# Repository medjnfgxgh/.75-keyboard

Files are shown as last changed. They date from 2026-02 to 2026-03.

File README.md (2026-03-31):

# .75-keyboard
An 83 key mechanical keyboard with a rotary encoder for volume and brightness. This was designed to be similar to a 75% keyboard.

### Why?
I was complaining to my friend about how terrible the keyboards in the computer labs at school are, and he suggested I bring my own. One problem, I don't have a spare keyboard. "Just make one", he said, "How hard could it be?". This was very clearly a joke but it did give me an idea for my next project, why not make my very own mechanical keyboard. It would test my CAD and PCB design skills, as well as my soldering, 3d printing and programming knowledge. After a little bit of research, I landed on my design with 83 keys and a rotary encoder.

8fcc9e12-a2cc-4154-a71c-1df4aa7ac567

## The design


## Schematic


## PCB


## Case
14d5399e-915a-4103-ba52-5c0a4543586c

# BOM
| Name | QTY | Cost | Link |
|---|-----|---|---|
|Rasberry Pi Pico welded C |  1  |$2.63 |[buy](https://www.aliexpress.com/item/1005005617180169.html)|
|Cherry MX switches |  9  |$2.33 |[buy](https://www.aliexpress.com/item/1005004341695529.html)|
|Stabilisers |  1  |$6.82 |[buy](https://www.aliexpress.com/item/1005007041109896.html)|
|Key Caps |  1  |$21.62|[buy](https://www.aliexpress.com/item/1005007360831985.html)|
|diodes |  1  |$4.48 |[buy](https://www.aliexpress.com/item/1005008994213870.html)|
|EC11 |  1  |$2.27 |[buy](https://www.aliexpress.com/item/1005007644083514.html)|
|Brass inserts |  1  |$4.56 |[buy](https://www.aliexpress.com/item/1005006071488810.html)|
|Screws |  1  |$6.38 |[buy](https://www.aliexpress.com/item/1005006674812661.html)|
|Female Headers |  1  |$3.34 |[buy](https://www.aliexpress.com/item/4001198421663.html)|
|subtotal |  1  |$73.07|
|Discounts |  1  |$-11.5|
|shipping |  1  |$7.39
|--------------------------|-----|------|-----|
|AliExpress total |  1  |$68.96|
|PCB |  1  |$35.32|
|--------------------------|-----|------|-----|
|TOTAL |  1  |$104.28|

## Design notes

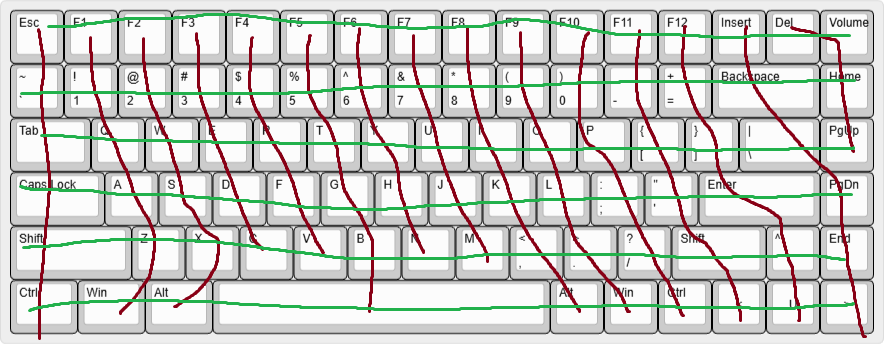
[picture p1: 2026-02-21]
Design/keyboard-layout-matrix.png

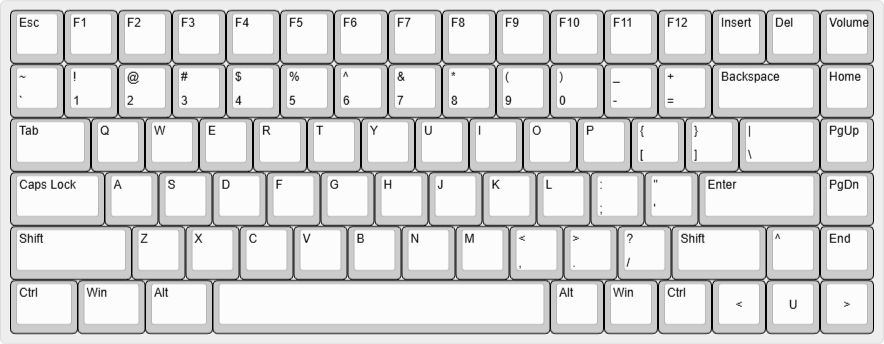
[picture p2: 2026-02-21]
Design/keyboard-layout.png

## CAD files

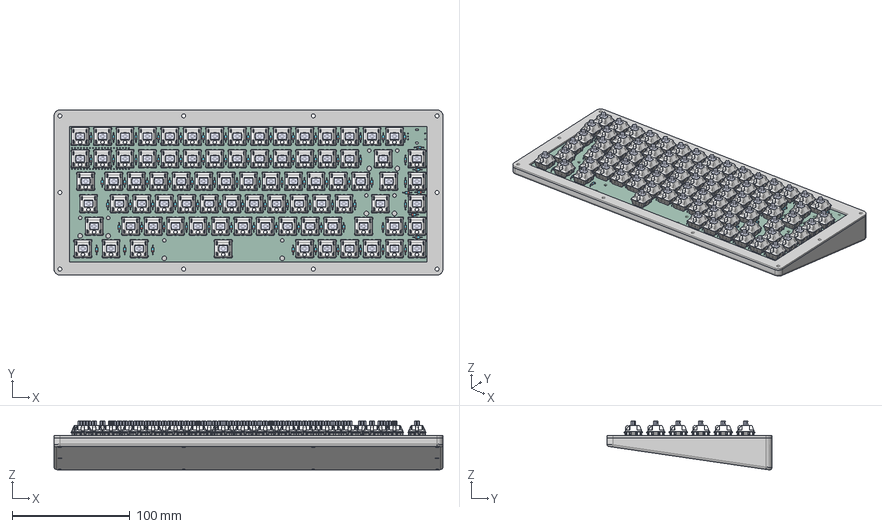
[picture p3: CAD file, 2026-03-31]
CAD/assembled.step
330.0 x 140.0 x 41.5 mm
D_DO-35_SOD27_P7.62mm_Horizontal x 84
Bottom x 83
Pulsador x 83
Top x 83
Pieza5^Cherry MX x 83
Pin1 x 83
Pin2 x 83
Led 3mm_trans x 83
PinSocket_1x20_P2.54mm_Vertical x 2
.75-keyboard-PCB_PCB

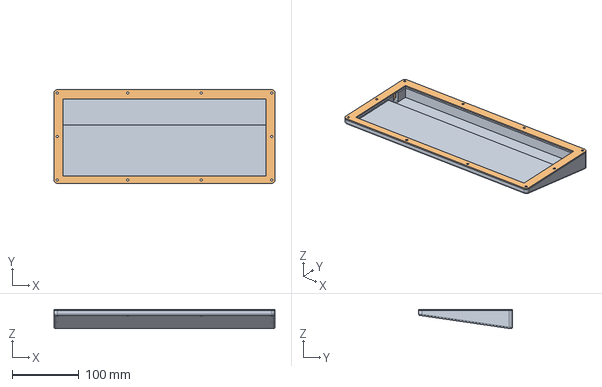
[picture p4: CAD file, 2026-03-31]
CAD/.75 keyboard cad.step
330.0 x 140.0 x 29.1 mm
base
Lid

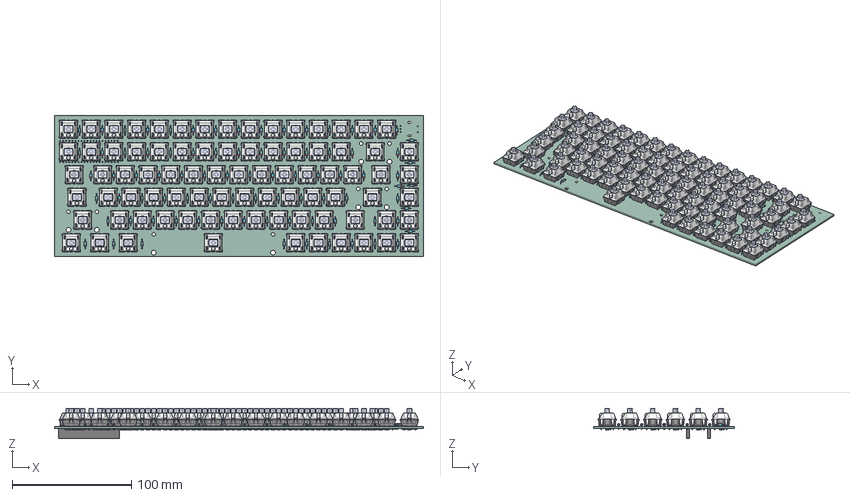
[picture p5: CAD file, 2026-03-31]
PCB/.75-keyboard-PCB.step
309.3 x 118.6 x 25.2 mm
D_DO-35_SOD27_P7.62mm_Horizontal x 84
Bottom x 82
Pulsador x 82
Top x 82
Pieza5^Cherry MX x 82
Pin1 x 82
Pin2 x 82
Led 3mm_trans x 82
PinSocket_1x20_P2.54mm_Vertical x 2
.75-keyboard-PCB_PCB

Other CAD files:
CAD/.75-keyboard-PCB.step

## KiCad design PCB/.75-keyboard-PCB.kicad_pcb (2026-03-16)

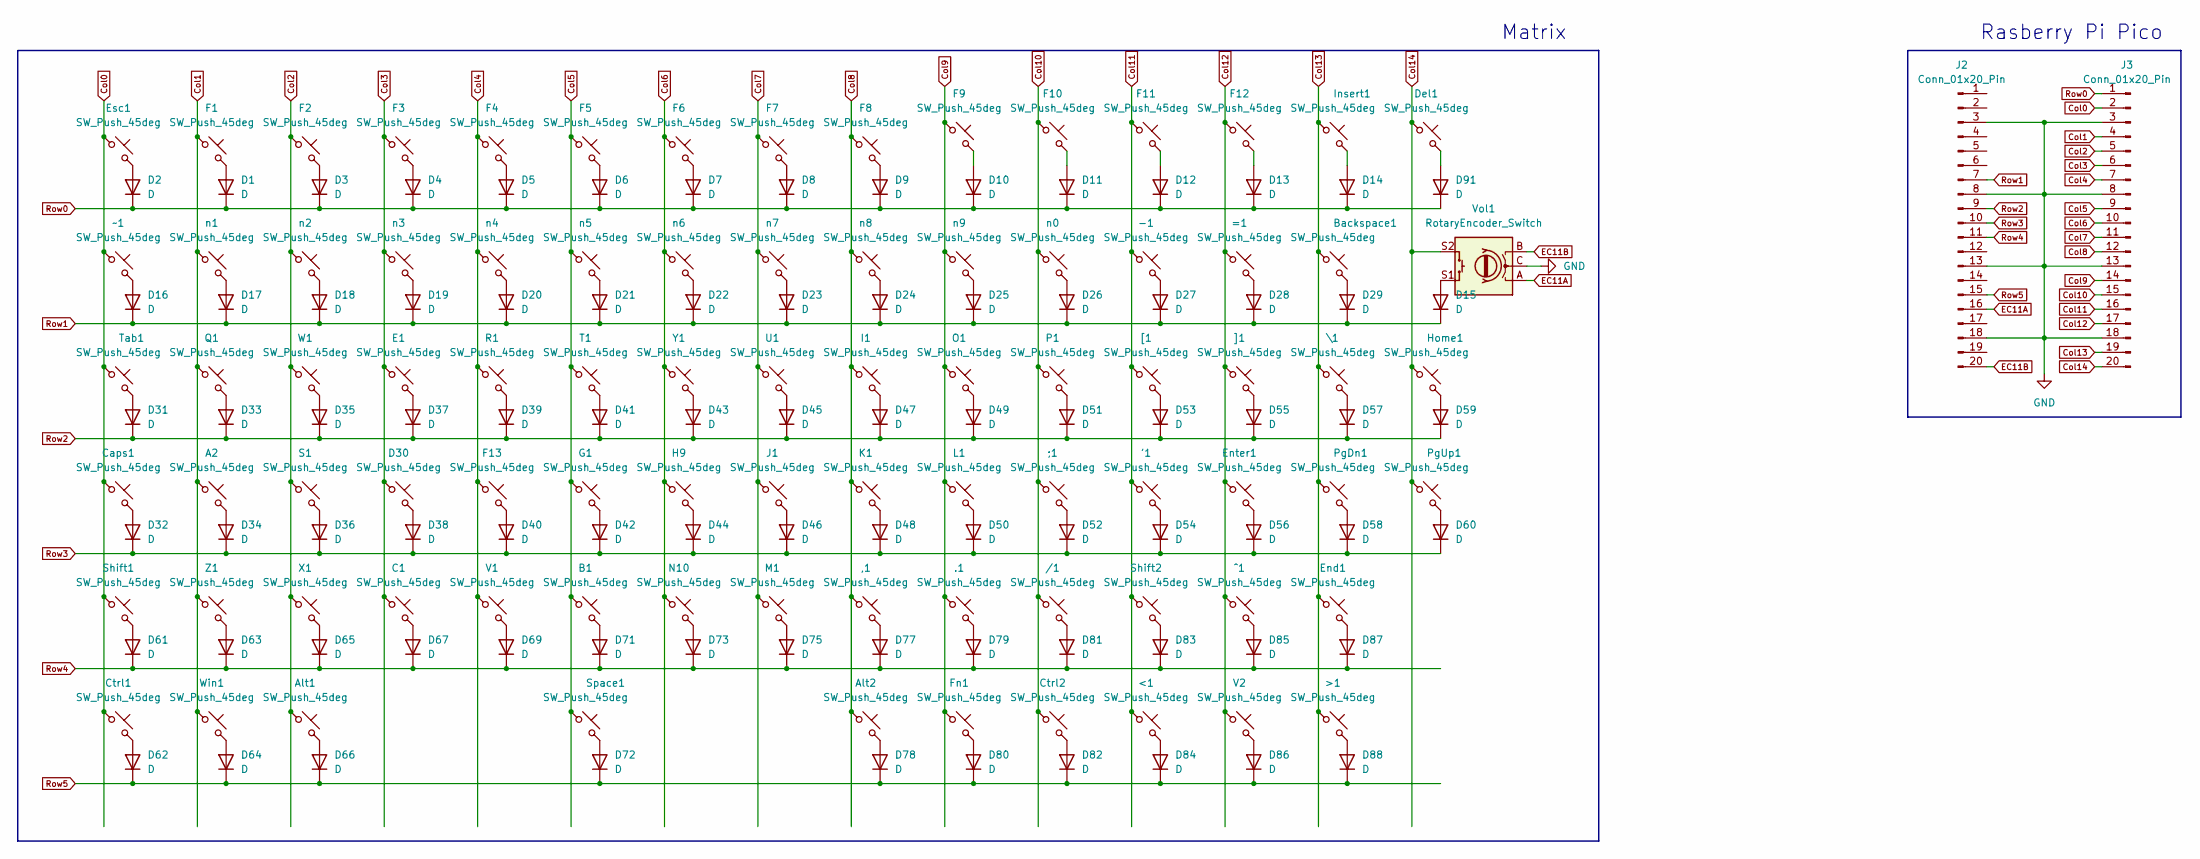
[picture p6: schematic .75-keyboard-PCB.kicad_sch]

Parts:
'1: SW_Push_45deg; 3DSW_Cherry_MX_1.00u_PCB
,1: SW_Push_45deg; 3DSW_Cherry_MX_1.00u_PCB
-1: SW_Push_45deg; 3DSW_Cherry_MX_1.00u_PCB
.1: SW_Push_45deg; 3DSW_Cherry_MX_1.00u_PCB
/1: SW_Push_45deg; 3DSW_Cherry_MX_1.00u_PCB
;1: SW_Push_45deg; 3DSW_Cherry_MX_1.00u_PCB
<1: SW_Push_45deg; 3DSW_Cherry_MX_1.00u_PCB
=1: SW_Push_45deg; 3DSW_Cherry_MX_1.00u_PCB
>1: SW_Push_45deg; 3DSW_Cherry_MX_1.00u_PCB
A2: SW_Push_45deg; 3DSW_Cherry_MX_1.00u_PCB
Alt1: SW_Push_45deg; 3DSW_Cherry_MX_1.25u_PCB
Alt2: SW_Push_45deg; 3DSW_Cherry_MX_1.00u_PCB
B1: SW_Push_45deg; 3DSW_Cherry_MX_1.00u_PCB
Backspace1: SW_Push_45deg; 3DSW_Cherry_MX_2.00u_PCB
C1: SW_Push_45deg; 3DSW_Cherry_MX_1.00u_PCB
Caps1: SW_Push_45deg; 3D_SW_Cherry_MX_1.75u_PCB
Ctrl1: SW_Push_45deg; 3DSW_Cherry_MX_1.25u_PCB
Ctrl2: SW_Push_45deg; 3DSW_Cherry_MX_1.00u_PCB
D1, D2, D3, D4, D5, D6, D7, D8, D9, D10, D11, D12, D13, D14, D15, D16, D17, D18, D19, D20, D21, D22, D23, D24, D25, D26, D27, D28, D29, D31, D32, D33, D34, D35, D36, D37, D38, D39, D40, D41, D42, D43, D44, D45, D46, D47, D48, D49, D50, D51, D52, D53, D54, D55, D56, D57, D58, D59, D60, D61, D62, D63, D64, D65, D66, D67, D69, D71, D72, D73, D75, D77, D78, D79, D80, D81, D82, D83, D84, D85, D86, D87, D88, D91: D; D_DO-35_SOD27_P7.62mm_Horizontal
D30: SW_Push_45deg; 3DSW_Cherry_MX_1.00u_PCB
Del1: SW_Push_45deg; 3DSW_Cherry_MX_1.00u_PCB
E1: SW_Push_45deg; 3DSW_Cherry_MX_1.00u_PCB
End1: SW_Push_45deg; 3DSW_Cherry_MX_1.00u_PCB
Enter1: SW_Push_45deg; 3DSW_Cherry_MX_2.25u_PCB
Esc1: SW_Push_45deg; 3DSW_Cherry_MX_1.00u_PCB
F1, F2, F3, F4, F5, F6, F7, F8, F9, F10, F11, F12, F13: SW_Push_45deg; 3DSW_Cherry_MX_1.00u_PCB
Fn1: SW_Push_45deg; 3DSW_Cherry_MX_1.00u_PCB
G1: SW_Push_45deg; 3DSW_Cherry_MX_1.00u_PCB
H9: SW_Push_45deg; 3DSW_Cherry_MX_1.00u_PCB
Home1: SW_Push_45deg; 3DSW_Cherry_MX_1.00u_PCB
I1: SW_Push_45deg; 3DSW_Cherry_MX_1.00u_PCB
Insert1: SW_Push_45deg; 3DSW_Cherry_MX_1.00u_PCB
J1: SW_Push_45deg; 3DSW_Cherry_MX_1.00u_PCB
J2, J3: Conn_01x20_Pin; PinSocket_1x20_P2.54mm_Vertical
K1: SW_Push_45deg; 3DSW_Cherry_MX_1.00u_PCB
L1: SW_Push_45deg; 3DSW_Cherry_MX_1.00u_PCB
M1: SW_Push_45deg; 3DSW_Cherry_MX_1.00u_PCB
N10: SW_Push_45deg; 3DSW_Cherry_MX_1.00u_PCB
O1: SW_Push_45deg; 3DSW_Cherry_MX_1.00u_PCB
P1: SW_Push_45deg; 3DSW_Cherry_MX_1.00u_PCB
PgDn1: SW_Push_45deg; 3DSW_Cherry_MX_1.00u_PCB
PgUp1: SW_Push_45deg; 3DSW_Cherry_MX_1.00u_PCB
Q1: SW_Push_45deg; 3DSW_Cherry_MX_1.00u_PCB
R1: SW_Push_45deg; 3DSW_Cherry_MX_1.00u_PCB
S1: SW_Push_45deg; 3DSW_Cherry_MX_1.00u_PCB
Shift1: SW_Push_45deg; 3DSW_Cherry_MX_2.25u_PCB
Shift2: SW_Push_45deg; 3D_SW_Cherry_MX_1.75u_PCB
Space1: SW_Push_45deg; 3DSW_Cherry_MX_6.25u_PCB
T1: SW_Push_45deg; 3DSW_Cherry_MX_1.00u_PCB
Tab1: SW_Push_45deg; 3DSW_Cherry_MX_1.50u_PCB
U1: SW_Push_45deg; 3DSW_Cherry_MX_1.00u_PCB
V1, V2: SW_Push_45deg; 3DSW_Cherry_MX_1.00u_PCB
Vol1: RotaryEncoder_Switch; RotaryEncoder_Alps_EC11E-Switch_Vertical_H20mm
W1: SW_Push_45deg; 3DSW_Cherry_MX_1.00u_PCB
Win1: SW_Push_45deg; 3DSW_Cherry_MX_1.25u_PCB
X1: SW_Push_45deg; 3DSW_Cherry_MX_1.00u_PCB
Y1: SW_Push_45deg; 3DSW_Cherry_MX_1.00u_PCB
Z1: SW_Push_45deg; 3DSW_Cherry_MX_1.00u_PCB
[1: SW_Push_45deg; 3DSW_Cherry_MX_1.00u_PCB
\1: SW_Push_45deg; 3DSW_Cherry_MX_1.50u_PCB
]1: SW_Push_45deg; 3DSW_Cherry_MX_1.00u_PCB
^1: SW_Push_45deg; 3DSW_Cherry_MX_1.00u_PCB
n0, n1, n2, n3, n4, n5, n6, n7, n8, n9: SW_Push_45deg; 3DSW_Cherry_MX_1.00u_PCB
~1: SW_Push_45deg; 3DSW_Cherry_MX_1.00u_PCB

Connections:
Col0: Caps1.1, Ctrl1.1, Esc1.1, J3.2, Shift1.1, Tab1.1, ~1.1
Col1: A2.1, F1.1, J3.4, Q1.1, Win1.1, Z1.1, n1.1
Col2: Alt1.1, F2.1, J3.5, S1.1, W1.1, X1.1, n2.1
Col3: C1.1, D30.1, E1.1, F3.1, J3.6, n3.1
Col4: F4.1, F13.1, J3.7, R1.1, V1.1, n4.1
Col5: B1.1, F5.1, G1.1, J3.9, Space1.1, T1.1, n5.1
Col6: F6.1, H9.1, J3.10, N10.1, Y1.1, n6.1
Col7: F7.1, J1.1, J3.11, M1.1, U1.1, n7.1
Col8: ,1.1, Alt2.1, F8.1, I1.1, J3.12, K1.1, n8.1
Col9: .1.1, F9.1, Fn1.1, J3.14, L1.1, O1.1, n9.1
Col10: /1.1, ;1.1, Ctrl2.1, F10.1, J3.15, P1.1, n0.1
Col11: '1.1, -1.1, <1.1, F11.1, J3.16, Shift2.1, [1.1
Col12: =1.1, Enter1.1, F12.1, J3.17, V2.1, ]1.1, ^1.1
Col13: >1.1, Backspace1.1, End1.1, Insert1.1, J3.19, PgDn1.1, \1.1
Col14: Del1.1, Home1.1, J3.20, PgUp1.1, Vol1.S2
EC11A: J2.16, Vol1.A
EC11B: J2.20, Vol1.B
GND: J2.3, J2.8, J2.13, J2.18, J3.3, J3.8, J3.13, J3.18, Vol1.C
unnamed: D1.2 (A), F1.2
unnamed: D2.2 (A), Esc1.2
unnamed: D3.2 (A), F2.2
unnamed: D4.2 (A), F3.2
unnamed: D5.2 (A), F4.2
unnamed: D6.2 (A), F5.2
unnamed: D7.2 (A), F6.2
unnamed: D8.2 (A), F7.2
unnamed: D9.2 (A), F8.2
unnamed: D10.2 (A), F9.2
unnamed: D11.2 (A), F10.2
unnamed: D12.2 (A), F11.2
unnamed: D13.2 (A), F12.2
unnamed: D14.2 (A), Insert1.2
unnamed: D15.2 (A), Vol1.S1
unnamed: D16.2 (A), ~1.2
unnamed: D17.2 (A), n1.2
unnamed: D18.2 (A), n2.2
unnamed: D19.2 (A), n3.2
unnamed: D20.2 (A), n4.2
unnamed: D21.2 (A), n5.2
unnamed: D22.2 (A), n6.2
unnamed: D23.2 (A), n7.2
unnamed: D24.2 (A), n8.2
unnamed: D25.2 (A), n9.2
unnamed: D26.2 (A), n0.2
unnamed: -1.2, D27.2 (A)
unnamed: =1.2, D28.2 (A)
unnamed: Backspace1.2, D29.2 (A)
unnamed: D31.2 (A), Tab1.2
unnamed: Caps1.2, D32.2 (A)
unnamed: D33.2 (A), Q1.2
unnamed: A2.2, D34.2 (A)
unnamed: D35.2 (A), W1.2
unnamed: D36.2 (A), S1.2
unnamed: D37.2 (A), E1.2
unnamed: D30.2, D38.2 (A)
unnamed: D39.2 (A), R1.2
unnamed: D40.2 (A), F13.2
unnamed: D41.2 (A), T1.2
unnamed: D42.2 (A), G1.2
unnamed: D43.2 (A), Y1.2
unnamed: D44.2 (A), H9.2
unnamed: D45.2 (A), U1.2
unnamed: D46.2 (A), J1.2
unnamed: D47.2 (A), I1.2
unnamed: D48.2 (A), K1.2
unnamed: D49.2 (A), O1.2
unnamed: D50.2 (A), L1.2
unnamed: D51.2 (A), P1.2
unnamed: ;1.2, D52.2 (A)
unnamed: D53.2 (A), [1.2
unnamed: '1.2, D54.2 (A)
unnamed: D55.2 (A), ]1.2
unnamed: D56.2 (A), Enter1.2
unnamed: D57.2 (A), \1.2
unnamed: D58.2 (A), PgDn1.2
unnamed: D59.2 (A), Home1.2
unnamed: D60.2 (A), PgUp1.2
unnamed: D61.2 (A), Shift1.2
unnamed: Ctrl1.2, D62.2 (A)
unnamed: D63.2 (A), Z1.2
unnamed: D64.2 (A), Win1.2
unnamed: D65.2 (A), X1.2
unnamed: Alt1.2, D66.2 (A)
unnamed: C1.2, D67.2 (A)
unnamed: D69.2 (A), V1.2
unnamed: B1.2, D71.2 (A)
unnamed: D72.2 (A), Space1.2
unnamed: D73.2 (A), N10.2
unnamed: D75.2 (A), M1.2
unnamed: ,1.2, D77.2 (A)
unnamed: Alt2.2, D78.2 (A)
unnamed: .1.2, D79.2 (A)
unnamed: D80.2 (A), Fn1.2
unnamed: /1.2, D81.2 (A)
unnamed: Ctrl2.2, D82.2 (A)
unnamed: D83.2 (A), Shift2.2
unnamed: <1.2, D84.2 (A)
unnamed: D85.2 (A), ^1.2
unnamed: D86.2 (A), V2.2
unnamed: D87.2 (A), End1.2
unnamed: >1.2, D88.2 (A)
unnamed: D91.2 (A), Del1.2
Row0: D1.1 (K), D2.1 (K), D3.1 (K), D4.1 (K), D5.1 (K), D6.1 (K), D7.1 (K), D8.1 (K), D9.1 (K), D10.1 (K), D11.1 (K), D12.1 (K), D13.1 (K), D14.1 (K), D91.1 (K), J3.1
Row1: D15.1 (K), D16.1 (K), D17.1 (K), D18.1 (K), D19.1 (K), D20.1 (K), D21.1 (K), D22.1 (K), D23.1 (K), D24.1 (K), D25.1 (K), D26.1 (K), D27.1 (K), D28.1 (K), D29.1 (K), J2.7
Row2: D31.1 (K), D33.1 (K), D35.1 (K), D37.1 (K), D39.1 (K), D41.1 (K), D43.1 (K), D45.1 (K), D47.1 (K), D49.1 (K), D51.1 (K), D53.1 (K), D55.1 (K), D57.1 (K), D59.1 (K), J2.9
Row3: D32.1 (K), D34.1 (K), D36.1 (K), D38.1 (K), D40.1 (K), D42.1 (K), D44.1 (K), D46.1 (K), D48.1 (K), D50.1 (K), D52.1 (K), D54.1 (K), D56.1 (K), D58.1 (K), D60.1 (K), J2.10
Row4: D61.1 (K), D63.1 (K), D65.1 (K), D67.1 (K), D69.1 (K), D71.1 (K), D73.1 (K), D75.1 (K), D77.1 (K), D79.1 (K), D81.1 (K), D83.1 (K), D85.1 (K), D87.1 (K), J2.11
Row5: D62.1 (K), D64.1 (K), D66.1 (K), D72.1 (K), D78.1 (K), D80.1 (K), D82.1 (K), D84.1 (K), D86.1 (K), D88.1 (K), J2.15

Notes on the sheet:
Matrix
Rasberry Pi Pico

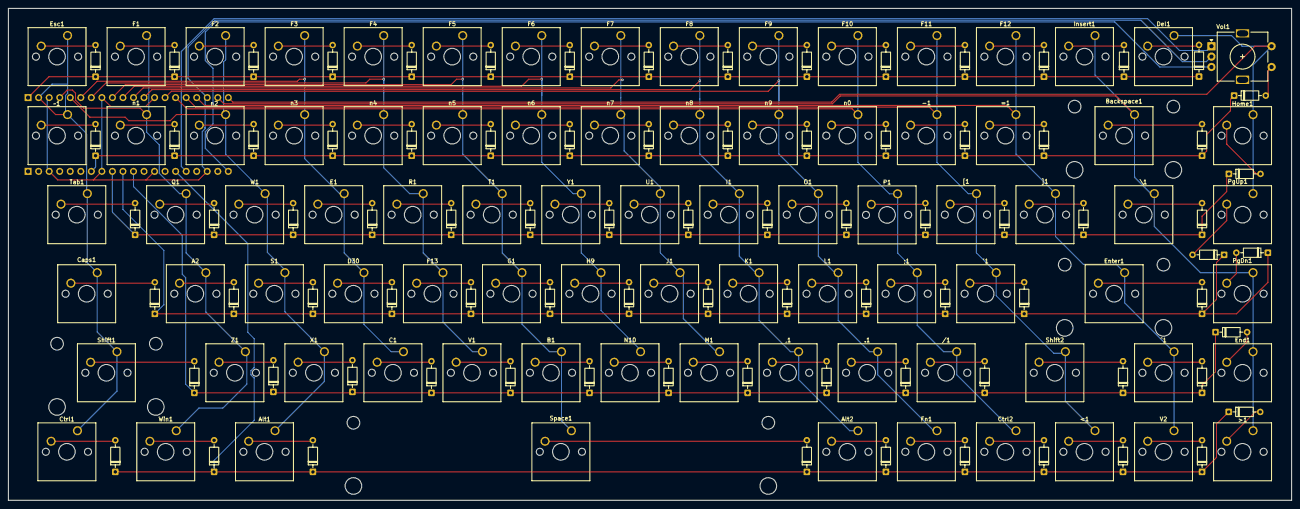
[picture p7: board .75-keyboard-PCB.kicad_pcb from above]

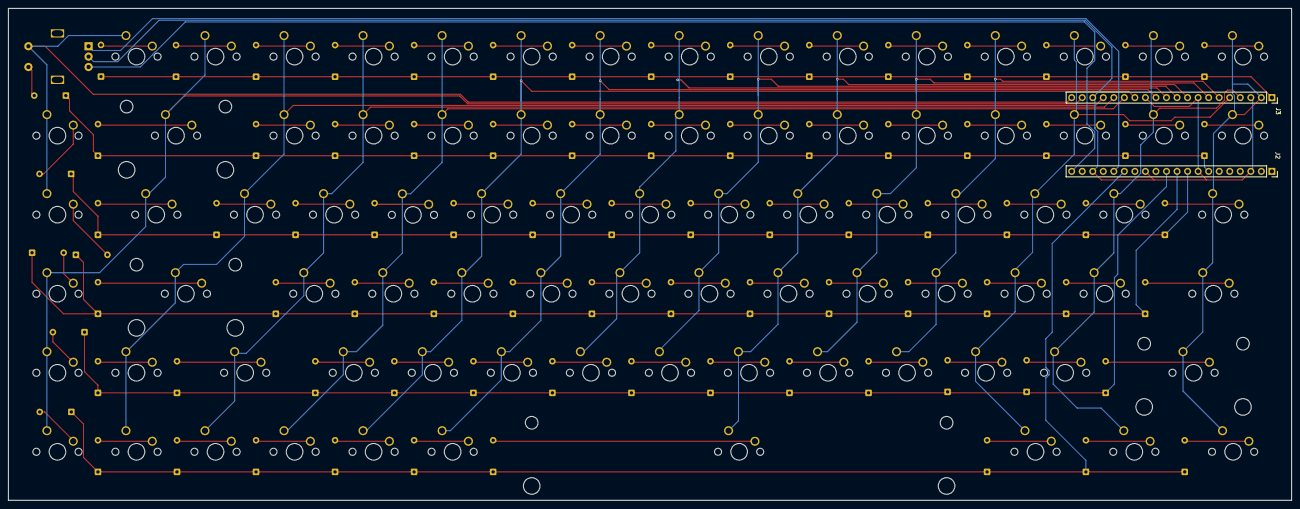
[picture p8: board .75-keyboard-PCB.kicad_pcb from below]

Board: 2 copper layers, 309.3 x 118.6 mm, 169 parts (2 on the bottom side), 107 nets.

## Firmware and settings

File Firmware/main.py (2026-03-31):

import board
from kmk.kmk_keyboard import KMKKeyboard
from kmk.keys import KC
from kmk.modules.encoder import EncoderHandler
from kmk.scanners import DiodeOrientation

keyboard = KMKKeyboard()


# MATRIX CONFIG


keyboard.col_pins = (
    board.GP0, board.GP1, board.GP2, board.GP3, board.GP4,
    board.GP5, board.GP6, board.GP7, board.GP8, board.GP9,
    board.GP10, board.GP11, board.GP12, board.GP13, board.GP14
)

keyboard.row_pins = (
    board.GP16, board.GP17, board.GP18,
    board.GP19, board.GP20, board.GP21
)

keyboard.diode_orientation = DiodeOrientation.COL2ROW


# ENCODER SETUP

encoder_handler = EncoderHandler()
keyboard.modules.append(encoder_handler)

# (A, B, Switch)
encoder_handler.pins = (
    (board.GP26, board.GP27, board.GP22),
)

# CCW, CW, Press
encoder_handler.map = [
    ((KC.VOLD, KC.VOLU, KC.MUTE),)
]

# KEYMAP

keyboard.keymap = [
    [
        KC.ESC,   KC.F1,    KC.F2,    KC.F3,    KC.F4,    KC.F5,    KC.F6,    KC.F7,    KC.F8,    KC.F9,    KC.F10,   KC.F11,   KC.F12,   KC.INS,   KC.DEL,   

        KC.GRV,   KC.N1,    KC.N2,    KC.N3,    KC.N4,    KC.N5,    KC.N6,    KC.N7,    KC.N8,    KC.N9,    KC.N0,    KC.MINS,  KC.EQL,   KC.BSPC,  KC.NO,

        KC.TAB,   KC.Q,     KC.W,     KC.E,     KC.R,     KC.T,     KC.Y,     KC.U,     KC.I,     KC.O,     KC.P,     KC.LBRC,  KC.RBRC,  KC.BSLS,  KC.HOME,

        KC.CAPS,  KC.A,     KC.S,     KC.D,     KC.F,     KC.G,     KC.H,     KC.J,     KC.K,     KC.L,     KC.SCLN,  KC.QUOT,  KC.ENT,   KC.NO,    KC.PGUP,

        KC.LSFT,  KC.Z,     KC.X,     KC.C,     KC.V,     KC.B,     KC.N,     KC.M,     KC.COMM,  KC.DOT,   KC.SLSH,  KC.RSFT,  KC.NO,    KC.UP,    KC.END,

        KC.LCTL,  KC.LGUI,  KC.LALT,   KC.SPC,  KC.SPC,   KC.SPC,   KC.SPC,   KC.SPC,   KC.SPC,   KC.RALT,  KC.RGUI,  KC.RCTL,  KC.LEFT,  KC.DOWN,  KC.RIGHT
    ]
]

# START

if __name__ == '__main__':
    keyboard.go()

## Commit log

2026-02-22 Schematic and mostly routed pcb
    [.75-keyboard-PCB.kicad_pcb, .75-keyboard-PCB.kicad_sch]
2026-03-05 pcb routing finished
    [.75-keyboard-PCB.kicad_pcb, .75-keyboard-PCB.kicad_sch]
2026-03-05 kicad switch models
    [.75-keyboard-PCB.kicad_pcb, .75-keyboard-PCB.kicad_sch]
2026-03-05 fix warnings
    repositioned labels to fix warnings
    [.75-keyboard-PCB.kicad_pcb]
2026-03-31 pcb step
    [.75-keyboard-PCB.step]
2026-03-31 upload STEP files
    [.75 keyboard cad.step, .75-keyboard-PCB.step, assembled.step]
